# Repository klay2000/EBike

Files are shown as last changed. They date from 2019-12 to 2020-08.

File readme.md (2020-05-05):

# Ebike

This repo contains the software and CAD files for my ebike.

## Software

All the software is currently written in Arduino and uses a few different libraries.

## Hardware

All the CAD files are made in Fusion 360/KiCAD and are put here in iges format/as a KiCAD project. At the moment my ebike runs a 48 volt 1500w brushless motor running at a maximum of 30 amps. My motor is powered by a FSESC motor controller, which I interface with over UART with a custom ESP32 board. My battery is a 48 volt 13AH li-ion Unit Pack Power battery pack.

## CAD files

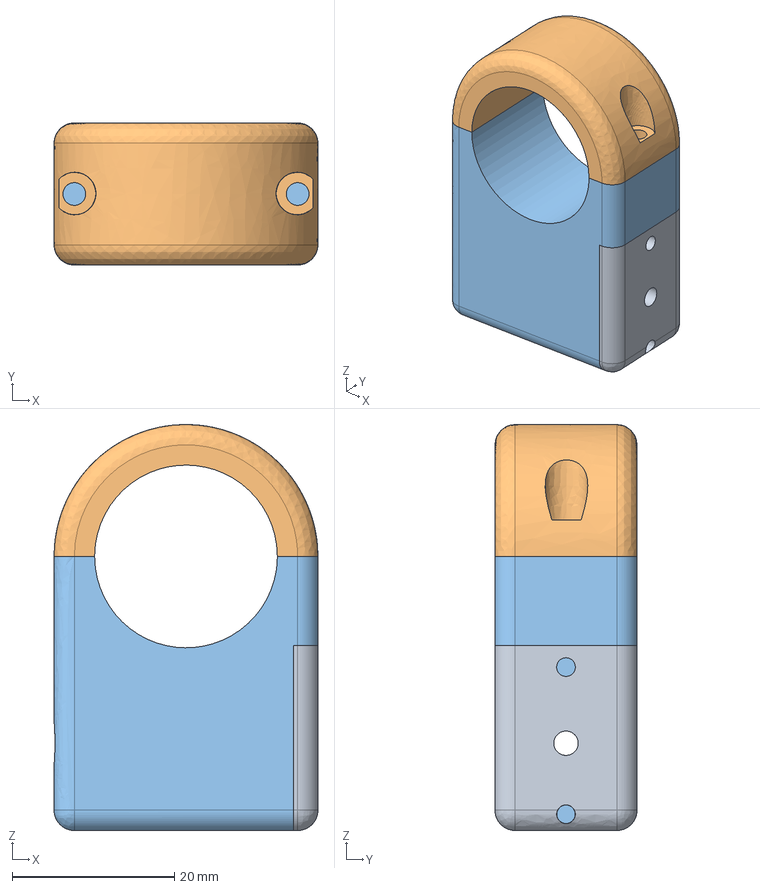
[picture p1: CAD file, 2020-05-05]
EBike CAD/Mechanical/Switch Mount.iges
32.5 x 17.5 x 50.0 mm

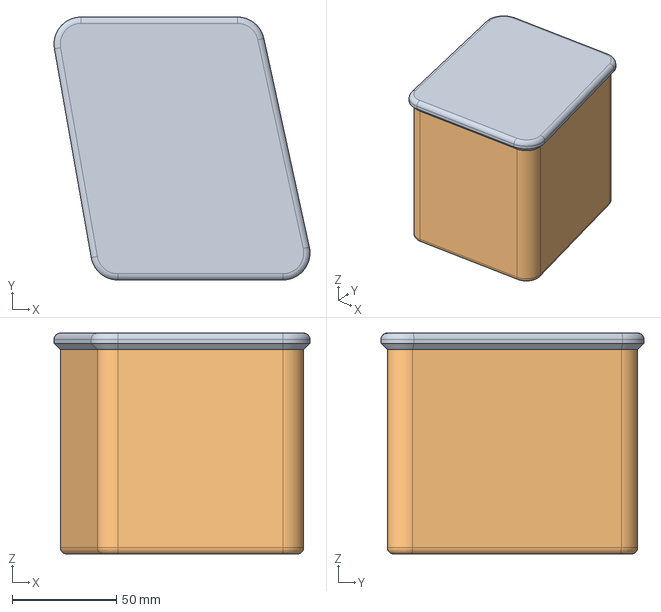
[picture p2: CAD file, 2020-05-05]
EBike CAD/Mechanical/Electrical Box.iges
122.8 x 126.2 x 106.0 mm

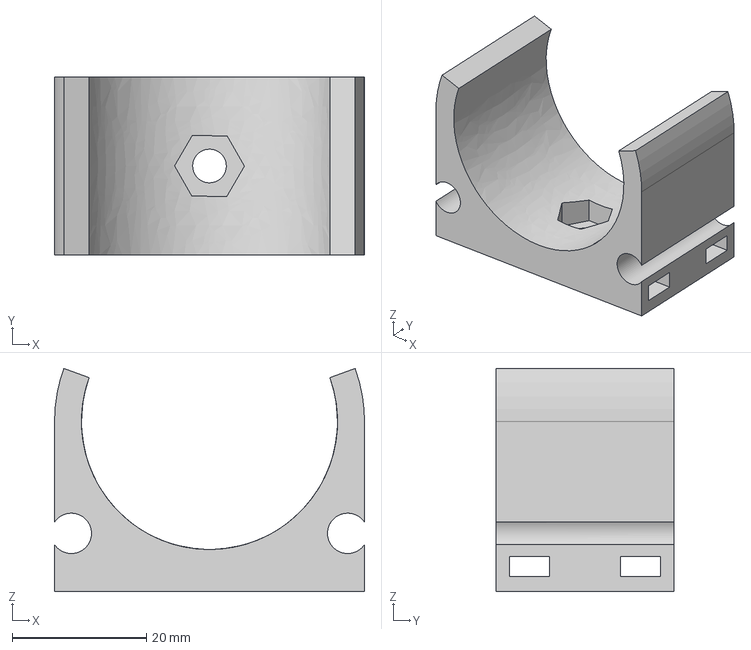
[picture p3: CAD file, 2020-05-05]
EBike CAD/Mechanical/Battery Frame Clip.iges
46.1 x 26.5 x 33.2 mm

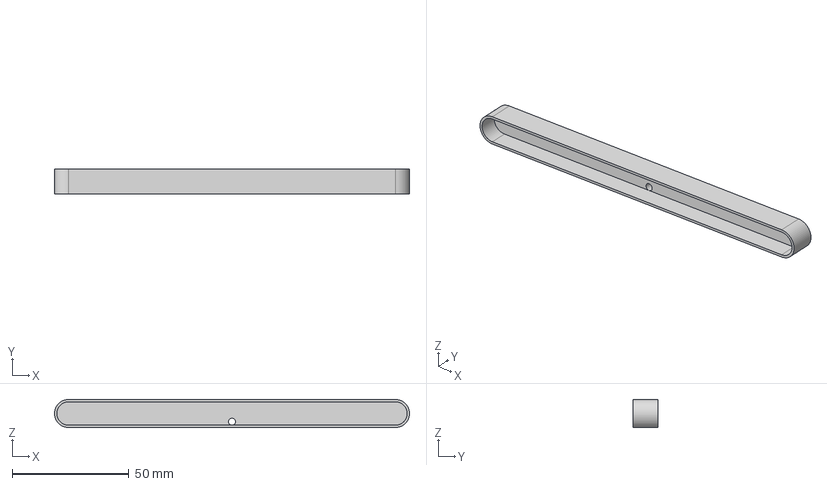
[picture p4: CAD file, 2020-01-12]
EBike CAD/Mechanical/Headlight Housing.iges
152.0 x 10.5 x 12.0 mm

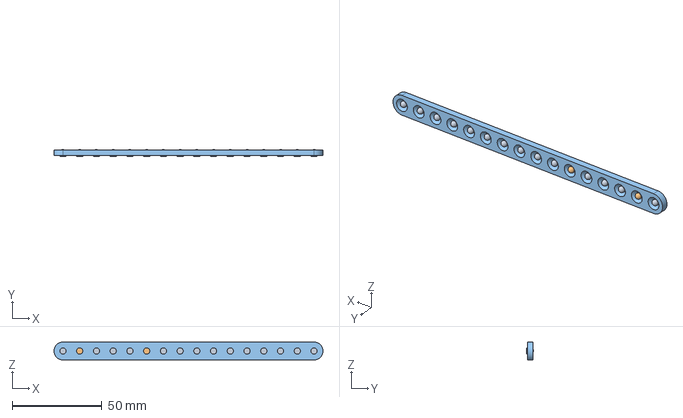
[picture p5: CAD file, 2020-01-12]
EBike CAD/Mechanical/Headlight.iges
150.0 x 4.00 x 10.0 mm

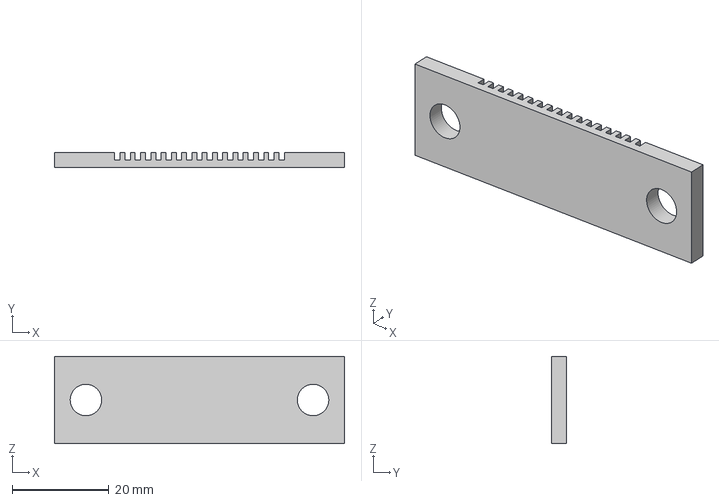
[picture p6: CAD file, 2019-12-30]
EBike CAD/Mechanical/VESC Heatsink Top.iges
60.0 x 3.18 x 18.0 mm

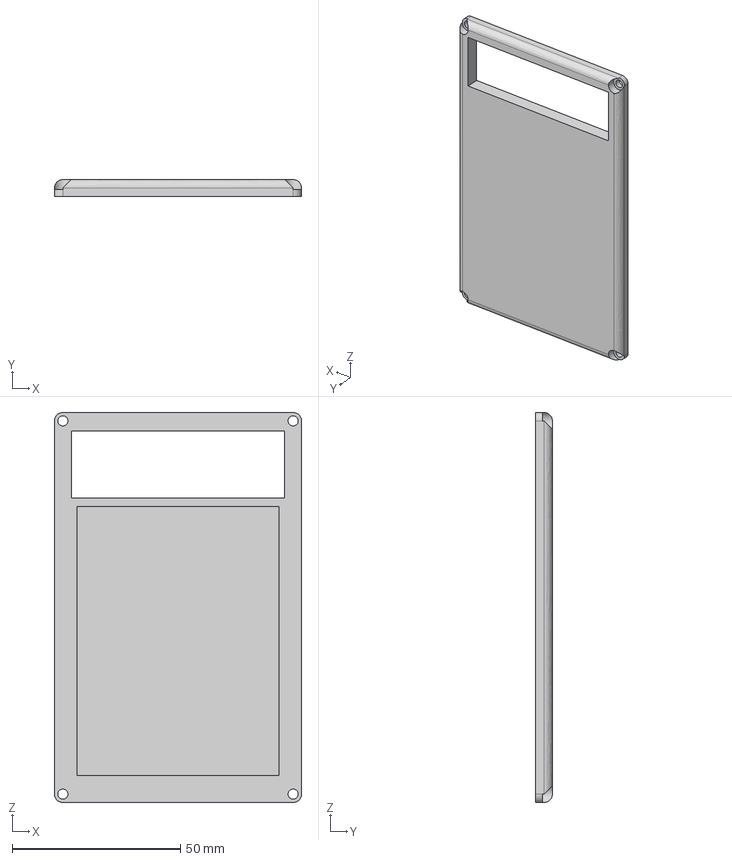
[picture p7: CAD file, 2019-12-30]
EBike CAD/Mechanical/VESC Case Top.iges
73.5 x 5.00 x 116.0 mm

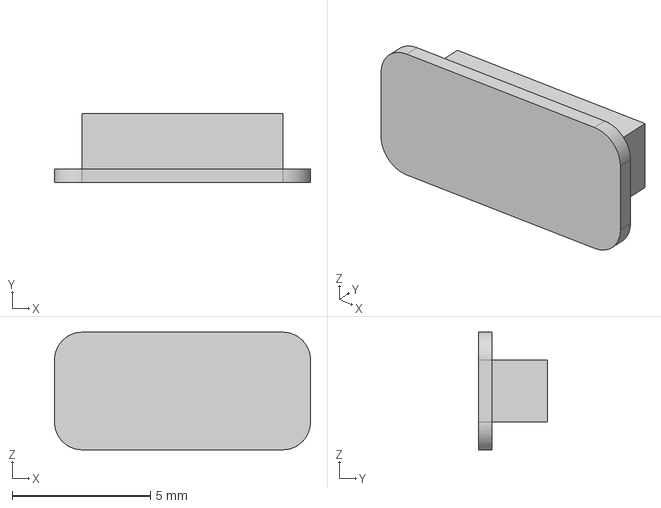
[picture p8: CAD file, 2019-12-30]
EBike CAD/Mechanical/Micro USB Dust Cover.iges
9.25 x 2.50 x 4.25 mm

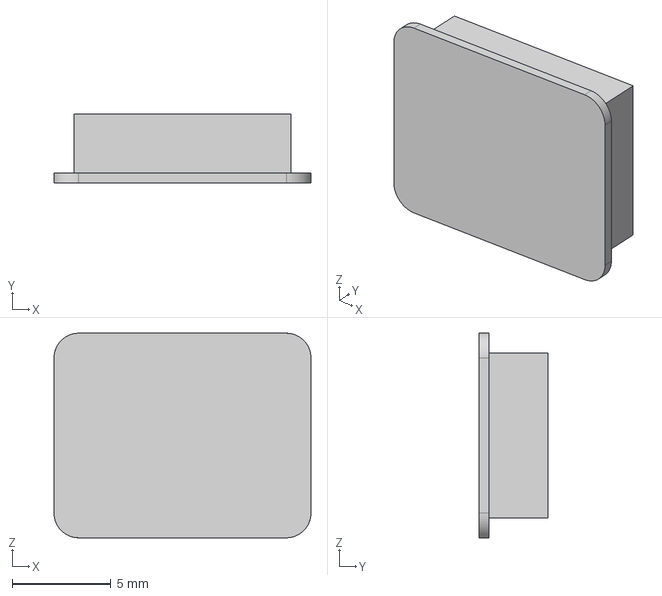
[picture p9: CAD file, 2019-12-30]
EBike CAD/Mechanical/Mini USB Dust Cover.iges
13.0 x 3.50 x 10.3 mm

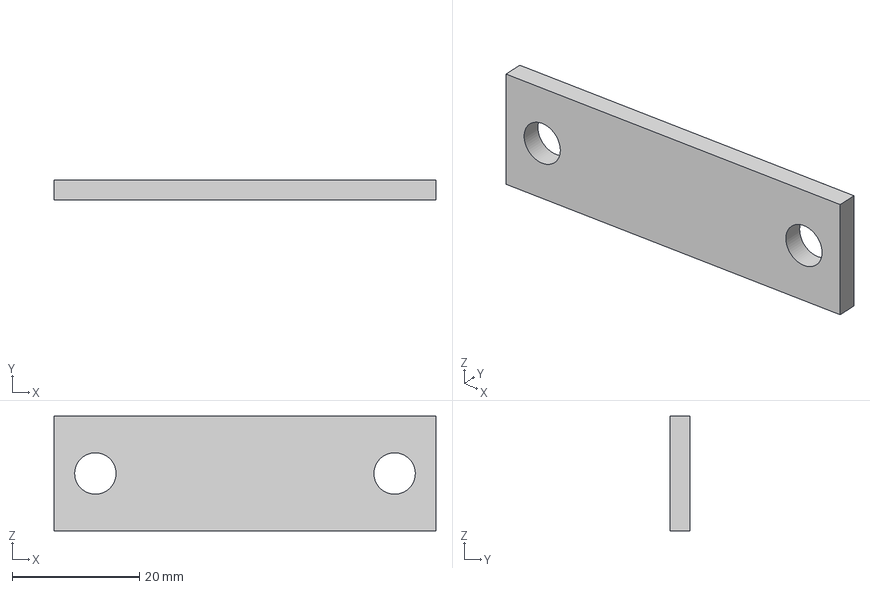
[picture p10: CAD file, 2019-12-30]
EBike CAD/Mechanical/VESC Heatsink Bottom.iges
60.0 x 3.18 x 18.0 mm

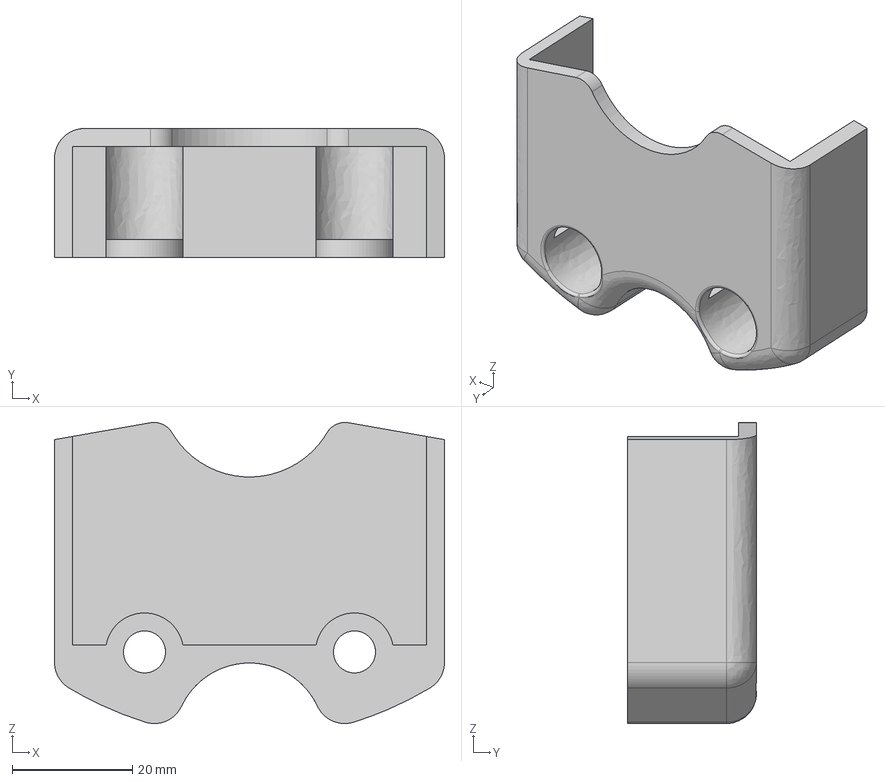
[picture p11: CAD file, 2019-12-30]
EBike CAD/Mechanical/Chain Guard.iges
65.0 x 21.5 x 50.2 mm

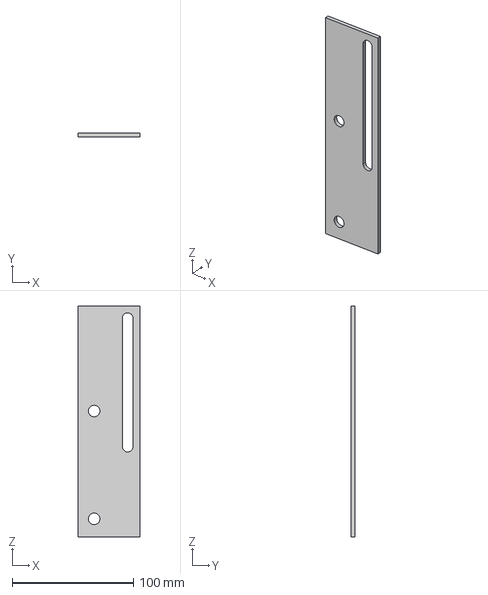
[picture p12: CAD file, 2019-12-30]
EBike CAD/Mechanical/Motor Mount.iges
50.8 x 3.18 x 190.5 mm

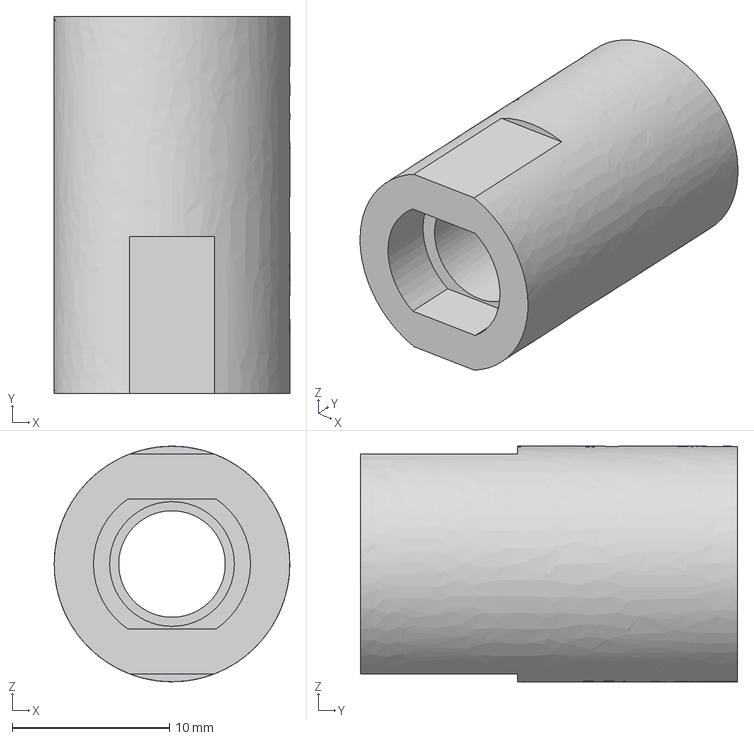
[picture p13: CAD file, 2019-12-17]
EBike CAD/Mechanical/Shaft Coupler.iges
15.0 x 24.0 x 15.0 mm

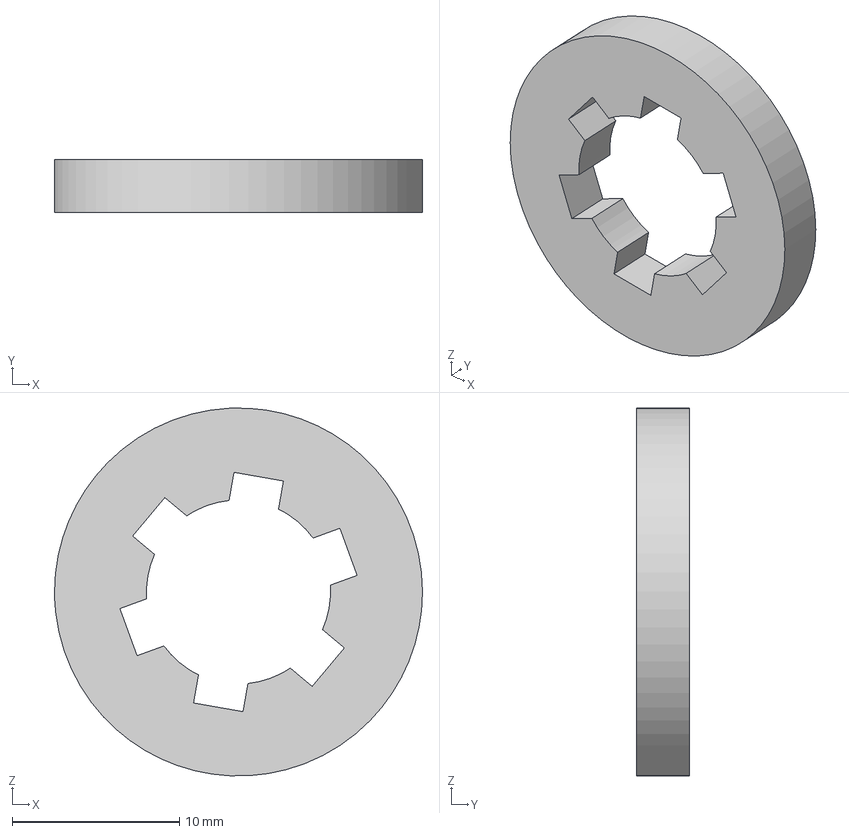
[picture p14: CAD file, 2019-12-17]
EBike CAD/Mechanical/Drive Sprocket Spacer.iges
22.0 x 3.18 x 22.0 mm

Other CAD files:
EBike CAD/Mechanical/Drive Sprocket.iges

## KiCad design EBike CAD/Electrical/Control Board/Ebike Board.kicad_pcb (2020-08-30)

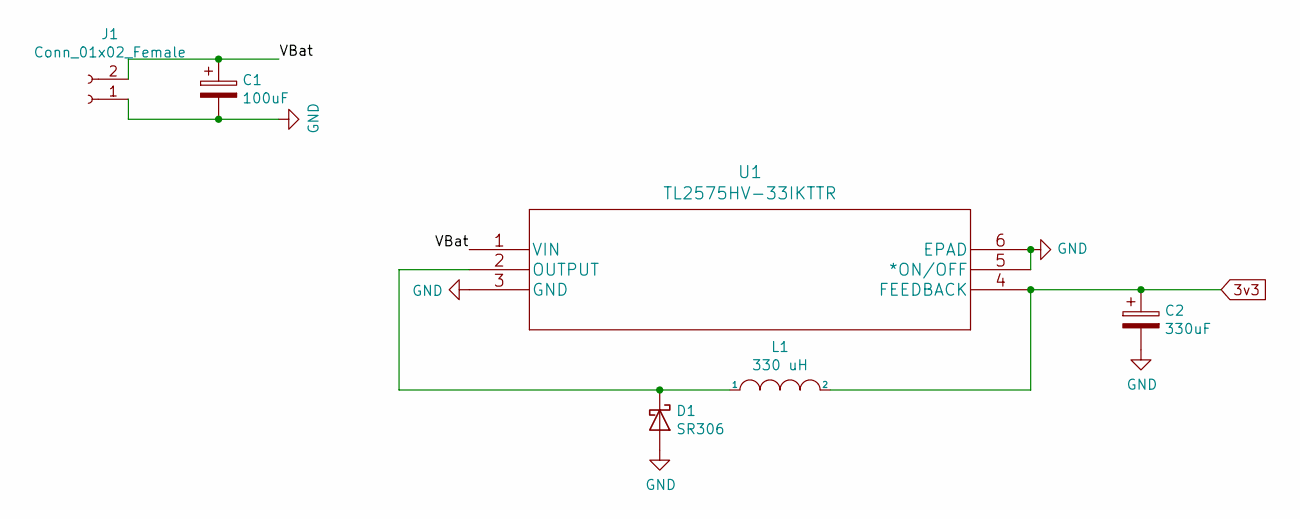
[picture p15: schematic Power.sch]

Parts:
C1: 100uF; CP_Radial_D10.0mm_P5.00mm
C2: 330uF; CP_Radial_D6.3mm_P2.50mm
D1: SR306; D_DO-201AD_P12.70mm_Horizontal
J1: Conn_01x02_Female; JST_XH_B2B-XH-AM_1x02_P2.50mm_Vertical
L1: 330 uH; L_Radial_D12.5mm_P7.00mm_Fastron_09HCP
U1: TL2575HV-33IKTTR; TO-263-5_TabPin6

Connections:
3v3: C2.1, L1.2, U1.4 (FEEDBACK); also elsewhere on the board
/Power/VBat: C1.1, J1.2, U1.1 (VIN)
GND: C1.2, C2.2, D1.2 (A), J1.1, U1.3 (GND), U1.5 (*ON/OFF), U1.6 (EPAD); also elsewhere on the board
unnamed: D1.1 (K), L1.1, U1.2 (OUTPUT)

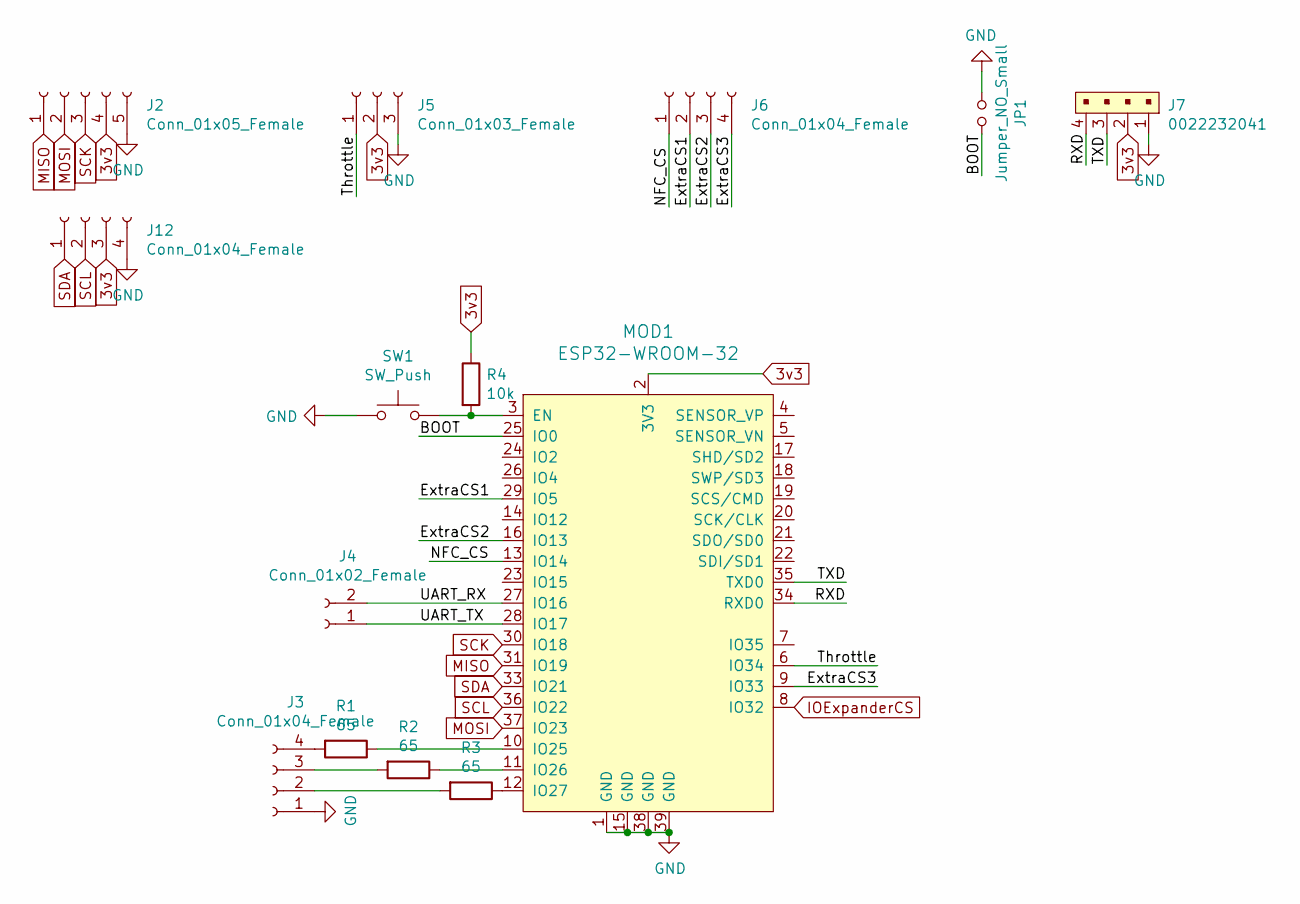
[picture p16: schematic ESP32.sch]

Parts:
J2: Conn_01x05_Female; JST_XH_B5B-XH-AM_1x05_P2.50mm_Vertical
J3, J6, J12: Conn_01x04_Female; JST_XH_B4B-XH-AM_1x04_P2.50mm_Vertical
J4: Conn_01x02_Female; JST_XH_B2B-XH-AM_1x02_P2.50mm_Vertical
J5: Conn_01x03_Female; JST_XH_B3B-XH-AM_1x03_P2.50mm_Vertical
J7: 0022232041; PinHeader_1x04_P2.54mm_Vertical; MPN 0022232041; Digi-Key_PN WM4202-ND
JP1: Jumper_NO_Small; PinHeader_1x02_P2.54mm_Vertical
MOD1: ESP32-WROOM-32; ESP32-WROOM-32D; MPN ESP32-WROOM-32; Digi-Key_PN 1904-1010-1-ND
R1, R2, R3: 65; R_1206_3216Metric_Pad1.42x1.75mm_HandSolder
R4: 10k; R_1206_3216Metric_Pad1.42x1.75mm_HandSolder
SW1: SW_Push; SW_PUSH_6mm

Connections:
3v3: J2.4, J5.2, J7.2, J12.3, MOD1.2 (3V3), R4.1; also elsewhere on the board
/ESP32/BOOT: JP1.2, MOD1.25 (IO0)
/ESP32/ExtraCS1: J6.2, MOD1.29 (IO5)
/ESP32/ExtraCS2: J6.3, MOD1.16 (IO13)
/ESP32/ExtraCS3: J6.4, MOD1.9 (IO33)
/ESP32/NFC_CS: J6.1, MOD1.13 (IO14)
/ESP32/RXD: J7.4, MOD1.34 (RXD0)
/ESP32/TXD: J7.3, MOD1.35 (TXD0)
/ESP32/Throttle: J5.1, MOD1.6 (IO34)
/ESP32/UART_RX: J4.2, MOD1.27 (IO16)
/ESP32/UART_TX: J4.1, MOD1.28 (IO17)
GND: J2.5, J3.1, J5.3, J7.1, J12.4, JP1.1, MOD1.1 (GND), MOD1.15 (GND), MOD1.38 (GND), MOD1.39 (GND), SW1.1; also elsewhere on the board
IOExpanderCS: MOD1.8 (IO32); also elsewhere on the board
MISO: J2.1, MOD1.31 (IO19); also elsewhere on the board
MOSI: J2.2, MOD1.37 (IO23); also elsewhere on the board
unnamed: J3.2, R3.2
unnamed: J3.3, R2.2
unnamed: J3.4, R1.2
unnamed: MOD1.3 (EN), R4.2, SW1.2
unnamed: MOD1.10 (IO25), R1.1
unnamed: MOD1.11 (IO26), R2.1
unnamed: MOD1.12 (IO27), R3.1
SCK: J2.3, MOD1.30 (IO18); also elsewhere on the board
SCL: J12.2, MOD1.36 (IO22)
SDA: J12.1, MOD1.33 (IO21)

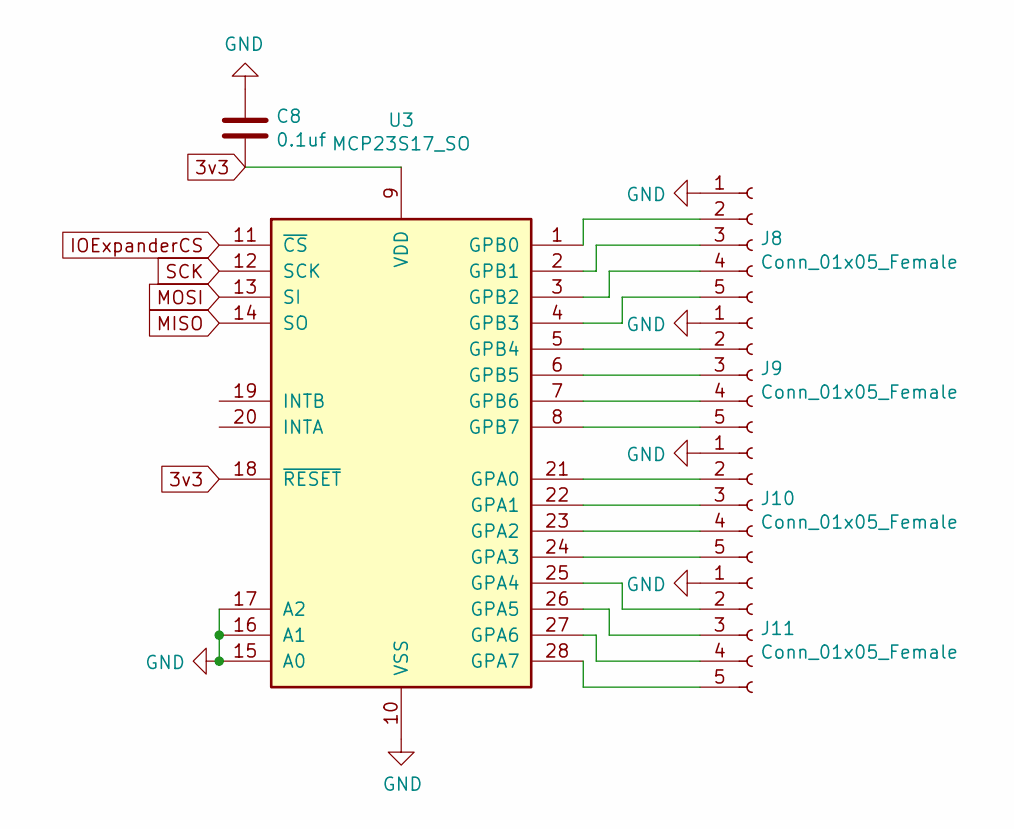
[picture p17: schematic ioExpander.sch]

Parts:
C8: 0.1uf; R_0201_0603Metric
J8, J9, J10, J11: Conn_01x05_Female; JST_XH_B5B-XH-AM_1x05_P2.50mm_Vertical
U3: MCP23S17_SO; SOIC-28W_7.5x17.9mm_P1.27mm

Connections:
3v3: C8.2, U3.9 (VDD), U3.18 (~RESET~); also elsewhere on the board
GND: C8.1, J8.1, J9.1, J10.1, J11.1, U3.10 (VSS), U3.15 (A0), U3.16 (A1), U3.17 (A2); also elsewhere on the board
IOExpanderCS: U3.11 (~CS~); also elsewhere on the board
MISO: U3.14 (SO); also elsewhere on the board
MOSI: U3.13 (SI); also elsewhere on the board
unnamed: J8.2, U3.1 (GPB0)
unnamed: J8.3, U3.2 (GPB1)
unnamed: J8.4, U3.3 (GPB2)
unnamed: J8.5, U3.4 (GPB3)
unnamed: J9.2, U3.5 (GPB4)
unnamed: J9.3, U3.6 (GPB5)
unnamed: J9.4, U3.7 (GPB6)
unnamed: J9.5, U3.8 (GPB7)
unnamed: J10.2, U3.21 (GPA0)
unnamed: J10.3, U3.22 (GPA1)
unnamed: J10.4, U3.23 (GPA2)
unnamed: J10.5, U3.24 (GPA3)
unnamed: J11.2, U3.25 (GPA4)
unnamed: J11.3, U3.26 (GPA5)
unnamed: J11.4, U3.27 (GPA6)
unnamed: J11.5, U3.28 (GPA7)
SCK: U3.12 (SCK); also elsewhere on the board

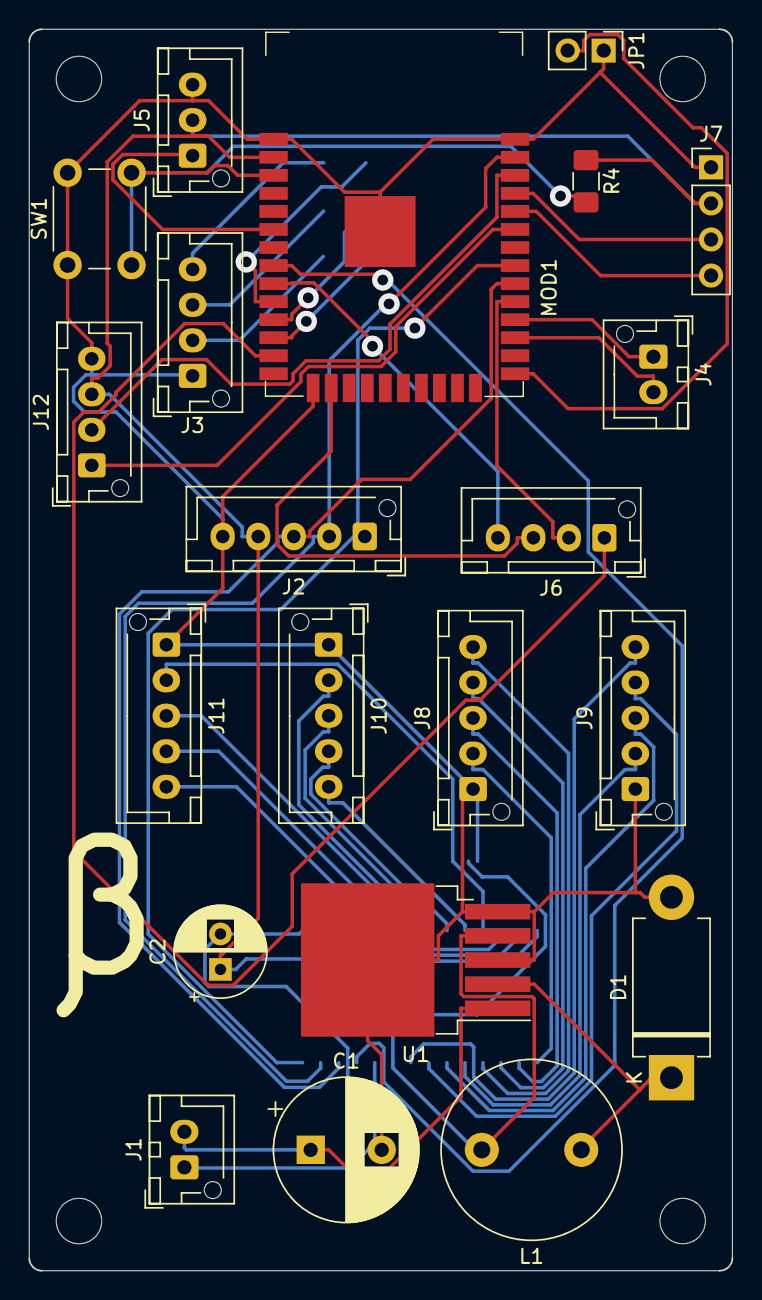
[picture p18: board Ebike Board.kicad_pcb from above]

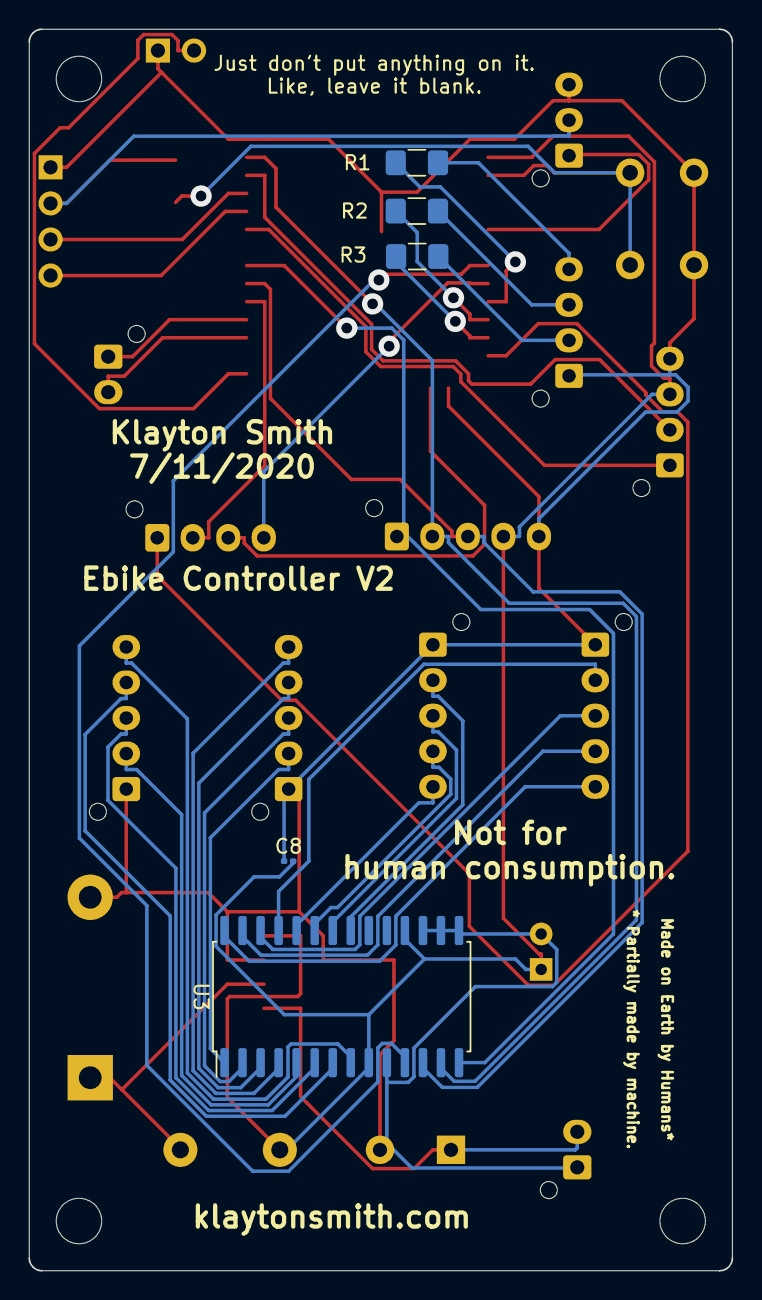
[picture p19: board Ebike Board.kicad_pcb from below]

Board: 2 copper layers, 49.5 x 87.4 mm, 30 parts (5 on the bottom side), 43 nets.

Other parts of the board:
mp1, mp2, mp3, mp4: MountingHole_3.2mm_M3

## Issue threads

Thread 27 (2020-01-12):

Implement Cluster

klay2000, 2020-01-12:
Implement screen "instrument cluster", should show amperage to motor, battery voltage, and other basic stats.

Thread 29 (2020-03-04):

Add CAD For Screen PCB

klay2000, 2020-03-04:
Some corrections need to be made as well.

Closed 2020-04-12.

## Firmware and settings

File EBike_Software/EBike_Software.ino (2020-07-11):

#include "Controls.h"
#include "Drive.h"
#include "Scheduler.h"
#include "CardReader.h"
#include "AuthTask.h"
#include "DriveTasks.h"
#include "OTATask.h"
#include "Bluetooth.h"
#include "IOExpander.h"
#include "Lights.h"
#include "LightsTask.h"
#include "FeedbackTasks.h"

Bluetooth* bt;
Controls* i;
Drive* d;
IOExpander* io;
Lights* l;
CardReader* c;

static void testTaskStart(void*){
}

static void testTask(void*)
{
  
//  bt->debugPrintln(String(d->getVolts()));
  l->setRed(1000);

}

Scheduler* scheduler;

void setup()
{

  bt =  Bluetooth::getInstance();

  i = Controls::getInstance();

  d = Drive::getInstance();

  io = IOExpander::getInstance();

  l = Lights::getInstance();

  c = CardReader::getInstance();

  scheduler = Scheduler::getInstance();

  Serial.begin(115200);

  scheduler->addTask(new Task(&testTaskStart, &testTask, 100));
  scheduler->addTask(new Task(&AuthTask::authTaskStart, &AuthTask::authTaskRun, 100));
  scheduler->addTask(new Task(&DriveTasks::throttleTaskStart, &DriveTasks::throttleTask, 10));
  scheduler->addTask(new Task(&OTATask::OTATaskStart, &OTATask::OTATaskRun, 200));
  scheduler->addTask(new Task(&LightsTask::lightsTaskStart, &LightsTask::lightsTaskRun, 50));
  scheduler->addTask(new Task(&FeedbackTasks::notificationLightTaskStart, &FeedbackTasks::notificationLightTaskRun, 20));
}

void loop()
{
  scheduler->tick();
}

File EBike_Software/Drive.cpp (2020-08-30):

#include "Drive.h"
#include "Controls.h"
#include <VescUart.h>
#include <Arduino.h>
#include "Bluetooth.h"

Drive* Drive::instance;

Drive::Drive(){
  Serial1.begin(115200);
  while(!Serial1);
   
  ESC.setSerialPort(&Serial1);
  ESC.setDebugPort(&Serial);

//temporary ppm
//  ledcAttachPin(17, 4);
//  ledcSetup(4, 50, 10);
}

Drive* Drive::getInstance(){
  if(instance == 0){
    instance = new Drive();
  }
  return instance;
}

float Drive::getAmps(){
//  if(ESC.getVescValues())
    return ESC.data.avgInputCurrent;
}


float Drive::getVolts(){
  if(ESC.getVescValues());
    return ESC.data.inpVoltage;
}

long Drive::getRPM(){
//  if(ESC.getVescValues());
    return ESC.data.rpm;
}

void Drive::setAmps(float a){
  ESC.setCurrent(constrain(a, 0, MAX_CURRENT));
  //temporary ppm
//  ledcWrite(4, constrain((a/MAX_CURRENT)*1023, 10, 1000)); 
  Bluetooth::getInstance()->debugPrintln(String(getVolts()));
//  Bluetooth::getInstance()->debugPrintln(String(ledcRead(4)));
}

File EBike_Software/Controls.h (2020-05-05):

#ifndef CONTROLS
#define CONTROLS

#include <Arduino.h>
  
class Controls{

  private:
    const int THROTTLE_PIN = 34;
    
    //on ioexpander
    const int KEY_PIN = 0;
    const int HEADLIGHT_PIN = 1;

    const int THROTTLE_MIN = 950;
    const int THROTTLE_MAX = 3000;

    const float THROTTLE_DEADBAND = 0.05f;

    static Controls* instance;
    Controls();
  

  public:
    static Controls* getInstance();
    float getThrottle();
    bool getKey();
    bool getHeadlight();
  
};

#endif

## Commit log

2019-10-17 Added CAD for Battery Clip. Changed readme to reflect new CAD.
    [Battery Clamp.scad, Battery Clamp.stl]
2019-10-19 fixed I think
    [Battery Clamp.scad, Battery Clamp.stl]
2019-10-20 Actually fixed CAD
    [Battery Clamp.scad, Battery Clamp.stl]
2019-11-20 converted cad to fusion, stored in iges format (#13)
    [Battery Clamp.scad, Battery Clamp.stl, Battery Frame Clip.iges]
2019-12-17 added cad (#19)
    [Adapter Plate.iges, Drive Sprocket Spacer.iges, Drive Sprocket.iges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]
2019-12-23 Motormount (#21)
    * v1
    * mount works
    [Motor Mount.iges]
2019-12-30 added A LOT of CAD (#23)
    [Chain Guard.iges, Micro USB Dust Cover.iges, Mini USB Dust Cover.iges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]
2020-01-12 headlight (#26)
    [Headlight Housing.iges, Headlight.iges]
2020-01-31 Stm32 case update (#28)
    * Updated STM-32 case to new version.
    [STM32 Case Bottom.iges, STM32 Case Top.iges]
2020-04-12 added controller
    [Adapter Plate.iges, Battery Frame Clip.iges, Chain Guard.iges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]
2020-04-12 Controller cad (#33)
    * stuff
    * stuff sorta runs, working on keycard
    * wrappers done
    * Added some stuff, bike drives.
    * finished noun classes
    * test
    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
    [Adapter Plate.iges, Battery Frame Clip.iges, Chain Guard.iges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]
2020-05-05 Software upgrades (#34)
    -Ported to custom ESP32 board
    -Added OTA updates
    -Added bluetooth serial debug
    -Added IOexpander
    -Added headlight functionality
    -Added keycard
    [Battery Frame Clip.iges, ESP32.sch, Ebike Board.kicad_pcb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]
2020-07-11 some hacks to fix broken uart and replace it with ppm
    [Ebike Board.kicad_pcb]
2020-07-19 new hw revision
    [Ebike Board.dsn, Ebike Board.kicad_pcb]
2020-07-19 routed pcb
    [Ebike Board.dsn, Ebike Board.kicad_pcb]
